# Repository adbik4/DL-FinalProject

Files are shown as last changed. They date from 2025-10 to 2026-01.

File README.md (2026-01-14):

# Dokumentacja projektu
## Schemat blokowy
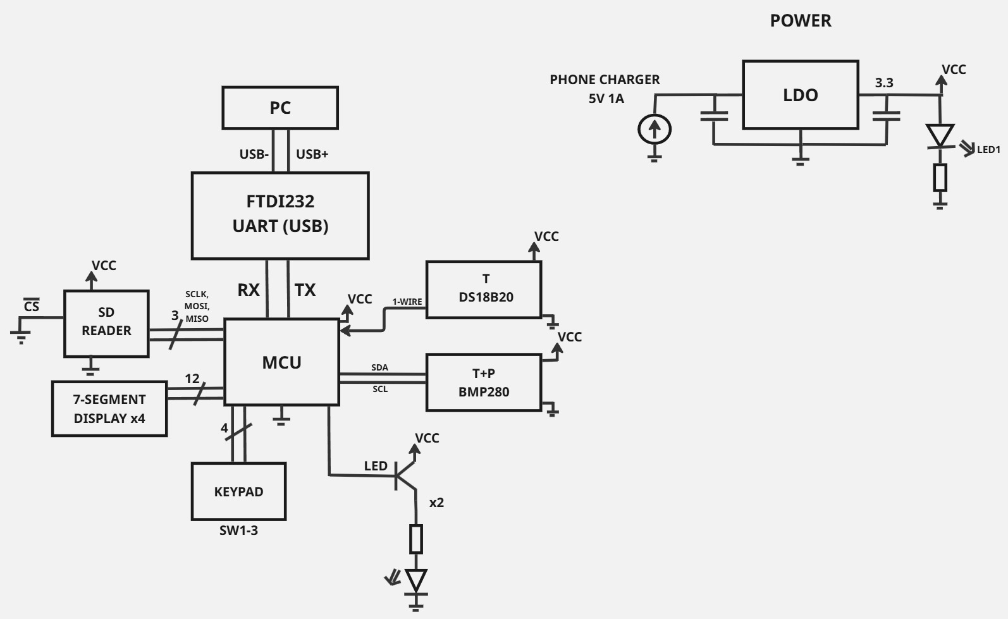
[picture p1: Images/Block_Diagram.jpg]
Schemat Blokowy


## Schemat ideowy
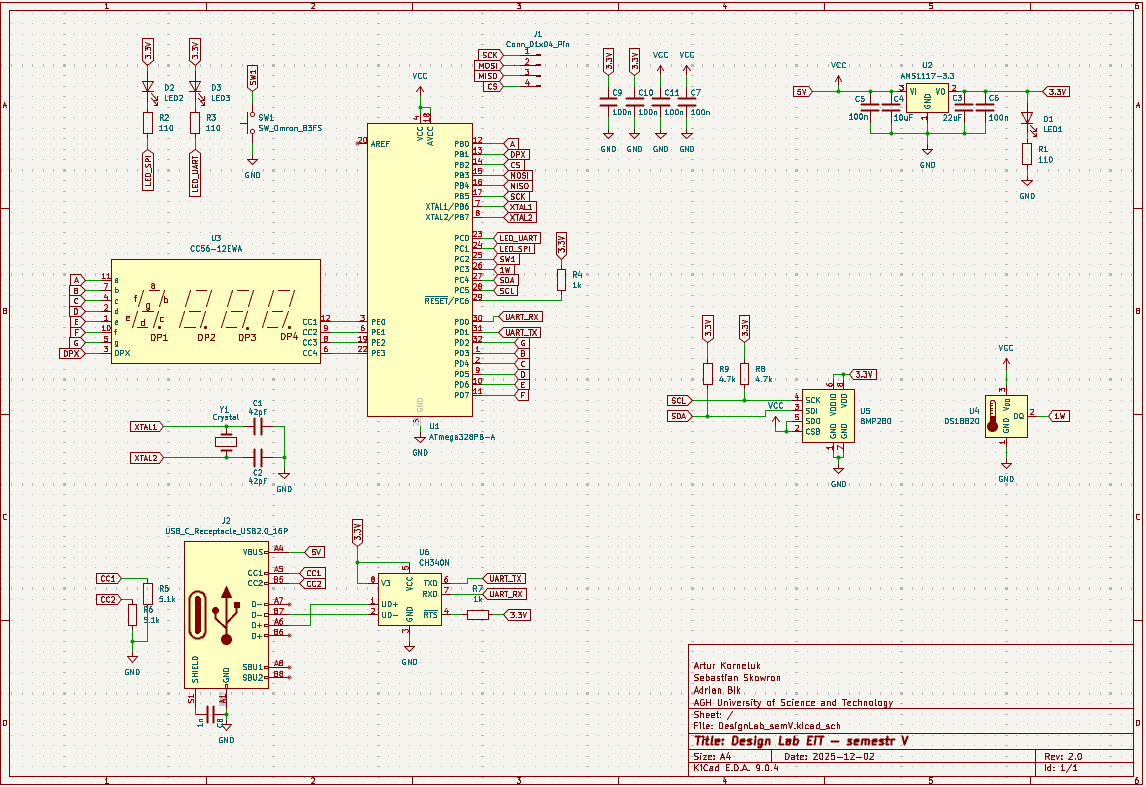
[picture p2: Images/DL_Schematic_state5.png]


## Design PCB
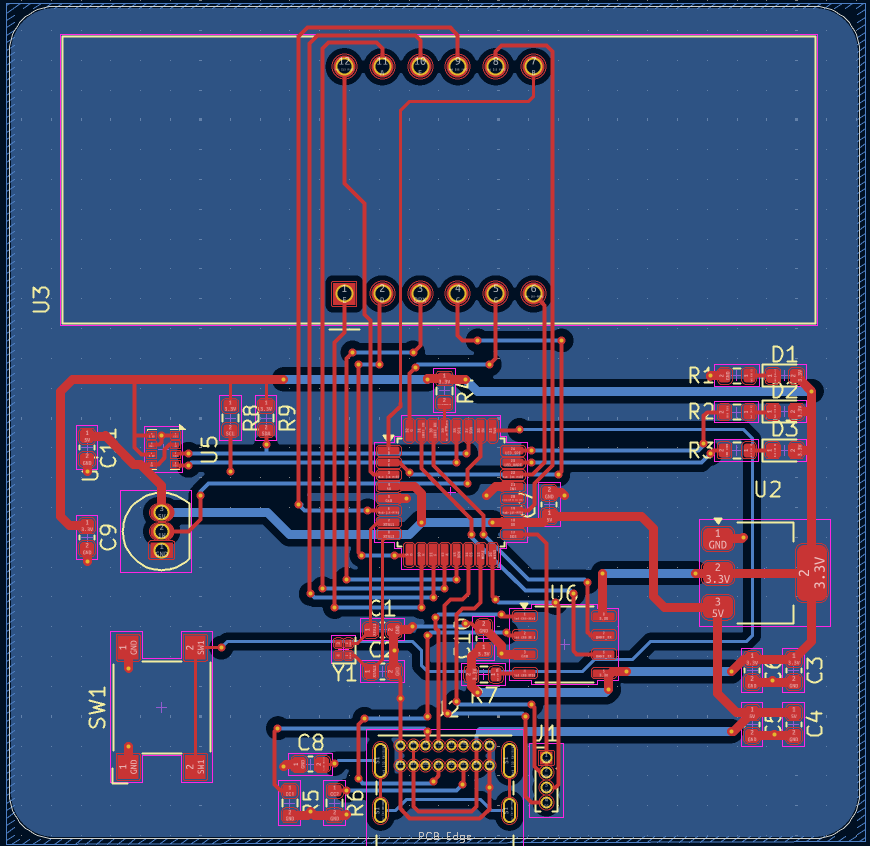
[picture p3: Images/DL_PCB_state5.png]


## Podgląd 3D
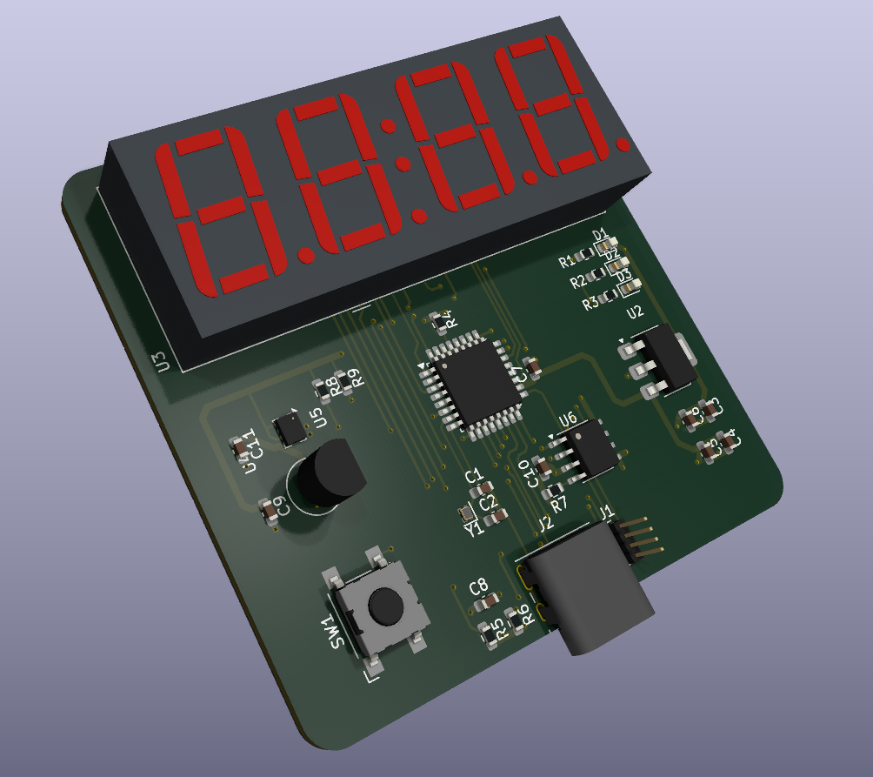
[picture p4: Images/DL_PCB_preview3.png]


### Blok mikrokontrolera (ATmega328PB)
*Obliczanie wartości pojemności C1 i C2 potrzebnych do zewnętrznego oscylatora MCU:*    

Wybraliśmy CY16BPS ponieważ jego parametry należą do najpopularniejszych do użycia w projektach z tym MCU.    
Oto jego najważniejsze parametry:   
- F_XTAL = 16 MHz
- C_load = 20 pF
- ESR = 50 ohm

Dla uproszczenia obliczeń, niech C1 = C2.    
Korzystając ze wzoru z dokumentacji ATmega,   
**C = 2 * C_L + C_S**  
gdzie     
C_L - Pojemnosć obciążenia kryształu,   
C_S - Pojemność pasożytnicza płytki PCB, niech wynosi 2 pF
    
Dla naszego kryształu C_L wynosi 20 pF    
**Stąd wynika, że C powinno mieć wartość około 42 pF.**

### Diody LED do sygnalizacji
*Obliczanie wartości rezystancji R1, R2 i R3 potrzebnych do uregulowania pracy diód:*     
    
Napięcie zasilania: 3.3V
Kolor diód LED: zielony co oznacza spadek napięcia około 2.2V   
Chcemy ustalić bezpieczny punkt pracy, powiedzmy 10mA    
Z prawa ohma: R = U / I = (3.3 - 2.2) / 10 mA = **110 ohm**

### Rezystancja podciągająca dla linii I2C
Wartość rezystancji podciągającej dla I2C jest wymianą pomiędzy możliwą prędkością wymiany danych a zużyciem energii.     

Zbyt mała wartość może uniemożliwić pinowi układu scalonego z którym się komunikujemy zwarcie linii z masą. Zalezy ona więc od najniższego napięcia jaka może być odczytana przez dany ukł. (U_OL) oraz prądu jaki jest on w stanie wytrzymać (I_OL).     

**R_min = (V_CC - U_OLmax) / I_OL**     

Zbyt duża zaś, przy dużych prędkościach może nie nadążyć z naładowaniem pojemności magistrali (C_m) przed nadejściem kolejnego stanu niskiego. W związku z tym, zależy ona od czasu narastania zboczy.     

**R_max = t_r / (0.8473 * C_m)**     
*Wartość 0.8473 = -ln(0.3) wynika z czasu ładowania pojemności od  30% - 70%*     

Przy naszych małych prędkościach komunikacji oraz z pojedynczym urządzeniem na magistrali, przyjmiemy standardową wartość **4.7kΩ.**

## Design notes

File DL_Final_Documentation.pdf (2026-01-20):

# AGH University of Krakow

# Documentation for the project

# Weather station

## from the course

# DESIGN LABORATORY

### Electronics and Telecommunications (PL), 3rd year

Adrian Bik | Sebastian Skowron | Artur Korneluk
| Thursday 8:00

Lecturer: dr inż. Jacek Stępień

15.01.2025

## 1. Project description

Project involves the design and implementation of a measurement and data logging system based on ATmega328pb microcontroller. The system is intended for measuring temperature and pressure using dedicated digital sensors: DS18B20 and BMP280. The captured data can be displayed on a 7-segment display and transmitted to a PC via USB-UART interface.
The system is designed in a modular way and implemented in stages, which allows for its gradual evolution and easy diagnostics of individual functional blocks. The project includes both hardware parts, such as schematic design and PCB layout, and software parts responsible for sensor handling, data presentation, data storage and user communication.

## 2. User manual

After a successful compilation, we can see the temperature from the BMP280 sensor displayed on a 7-segment display connected to the microcontroller. After a short press and hold of the S1 button on the keyboard, the pressure value is being displayed. Repeating this action, we get a temperature value from DS18B20 sensor, then we can come back to the first read. The UART-USB converter is used in order to enable communication between two PC`s by UART standard. We can receive the data from the sensors in terminal and additionally send messages from PC1 to PC2 (echo action).

## 3. Source files

Microchip Studio project contains:

- main.c, main.h - Main program of the project
- diodes.c, diodes.h - Led diodes control
- display.c, display.h - 7-segment display code
- uart.c, uart.h - Communication by UART standard
- sensors.c, sensors.h - BMP280, DS18B20 temperature and pressure sensors control

## 4. User Interface

The custom user interface designed for the weather station was written in the Python programming language. The application enables communication with the measurement device via serial COM port, while the current connection status is clearly presented to the user through a connected / disconnected status message.
The interface displays real-time measurement data captured from the weather station sensors, including temperature and pressure. These values are presented in standard physical units. Additionally, the application includes a log section that displays raw data frames received from the microcontroller. The interface also allows for sending custom text commands, enabling full diagnostics of the UART communication.
The current interface architecture provides a solid basis for further system development, such as adding data logging to files or visualizing measurements using charts.

## 5. PCB

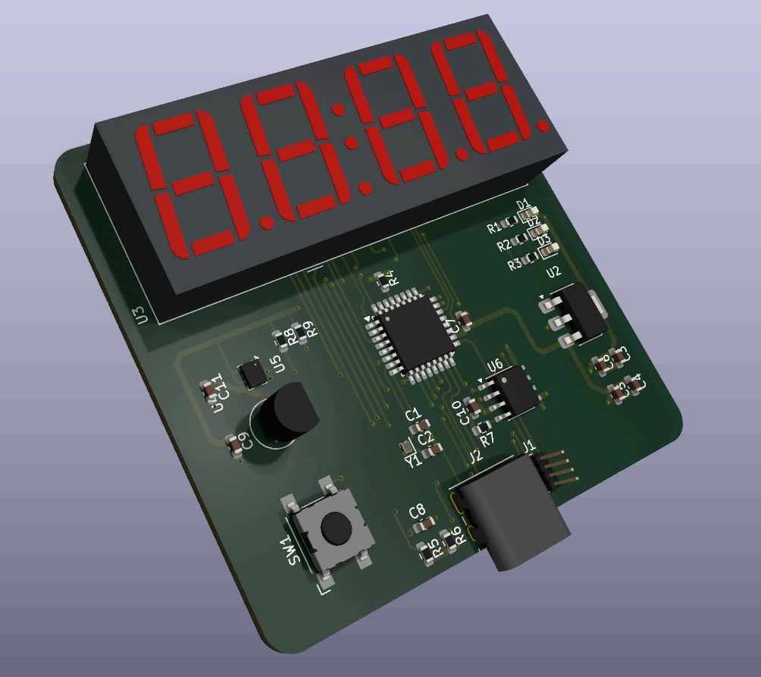
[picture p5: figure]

The full hardware documentation is located on github.
https://github.com/adbik4/DL-FinalProject

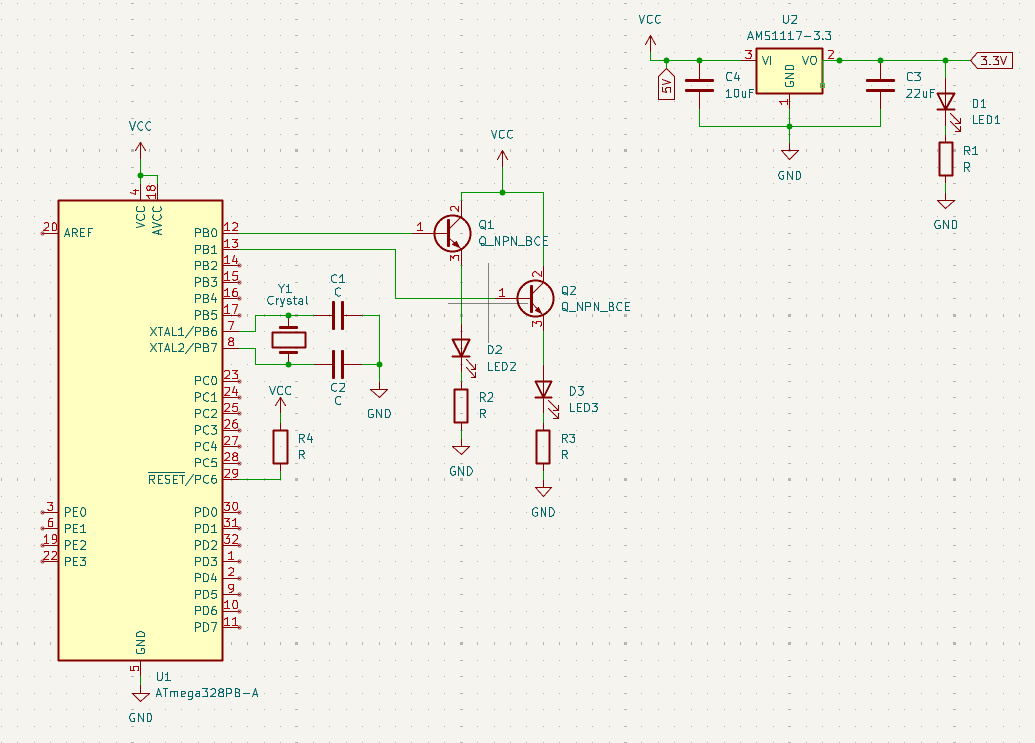
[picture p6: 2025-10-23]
Images/DL_Schematic_state1.png

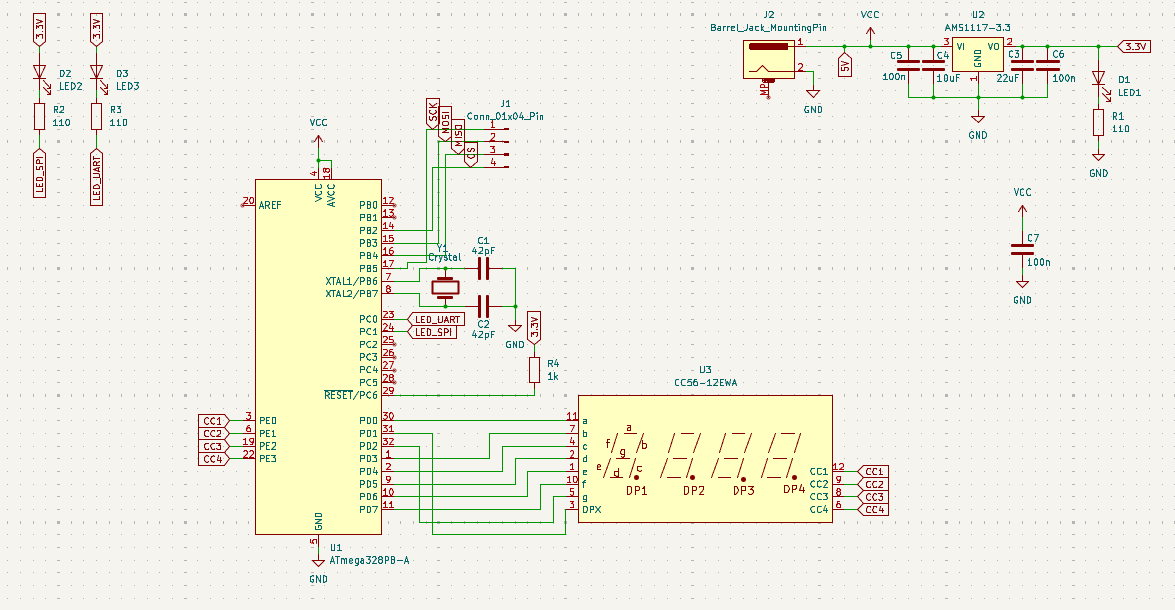
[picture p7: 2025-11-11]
Images/DL_Schematic_state3.png

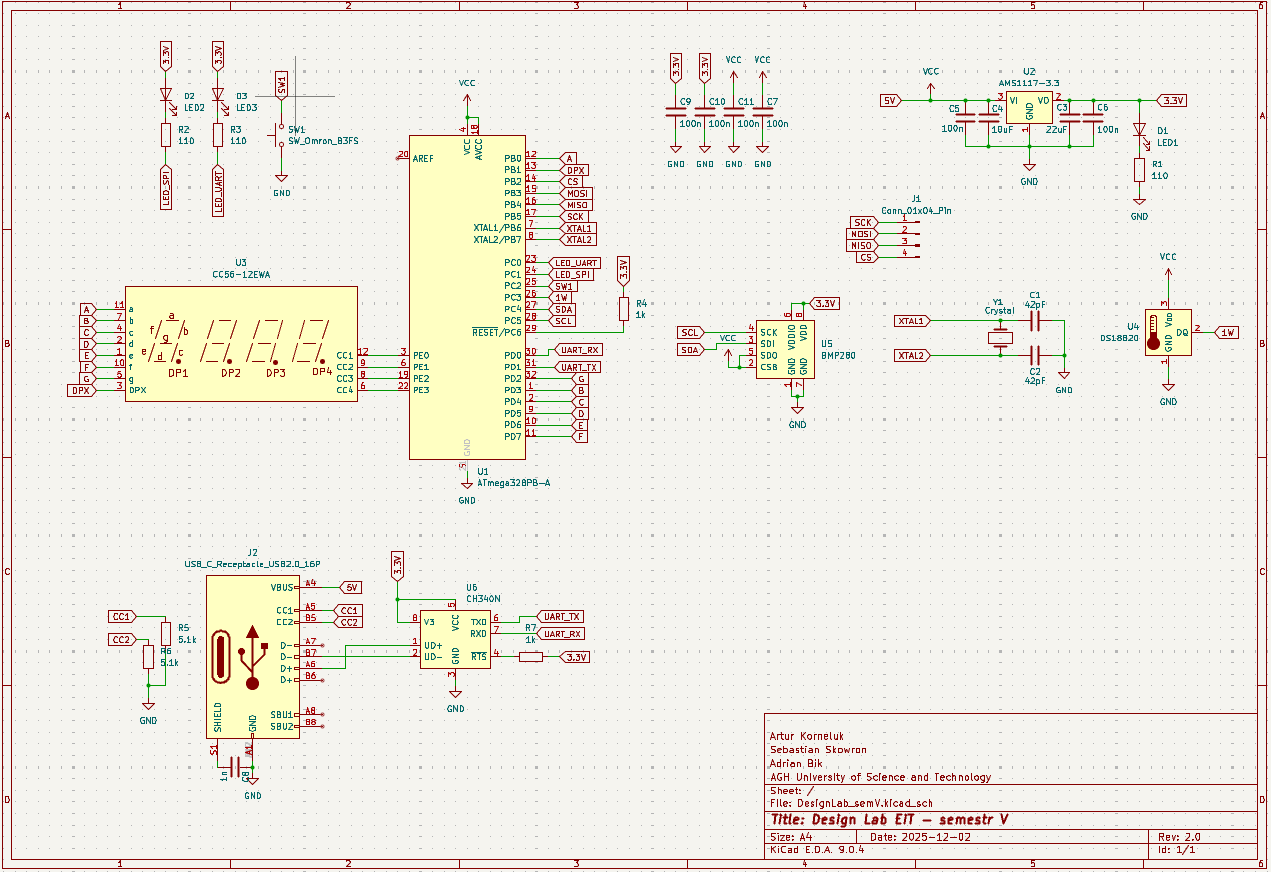
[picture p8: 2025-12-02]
Images/DL_Schematic_state4.png

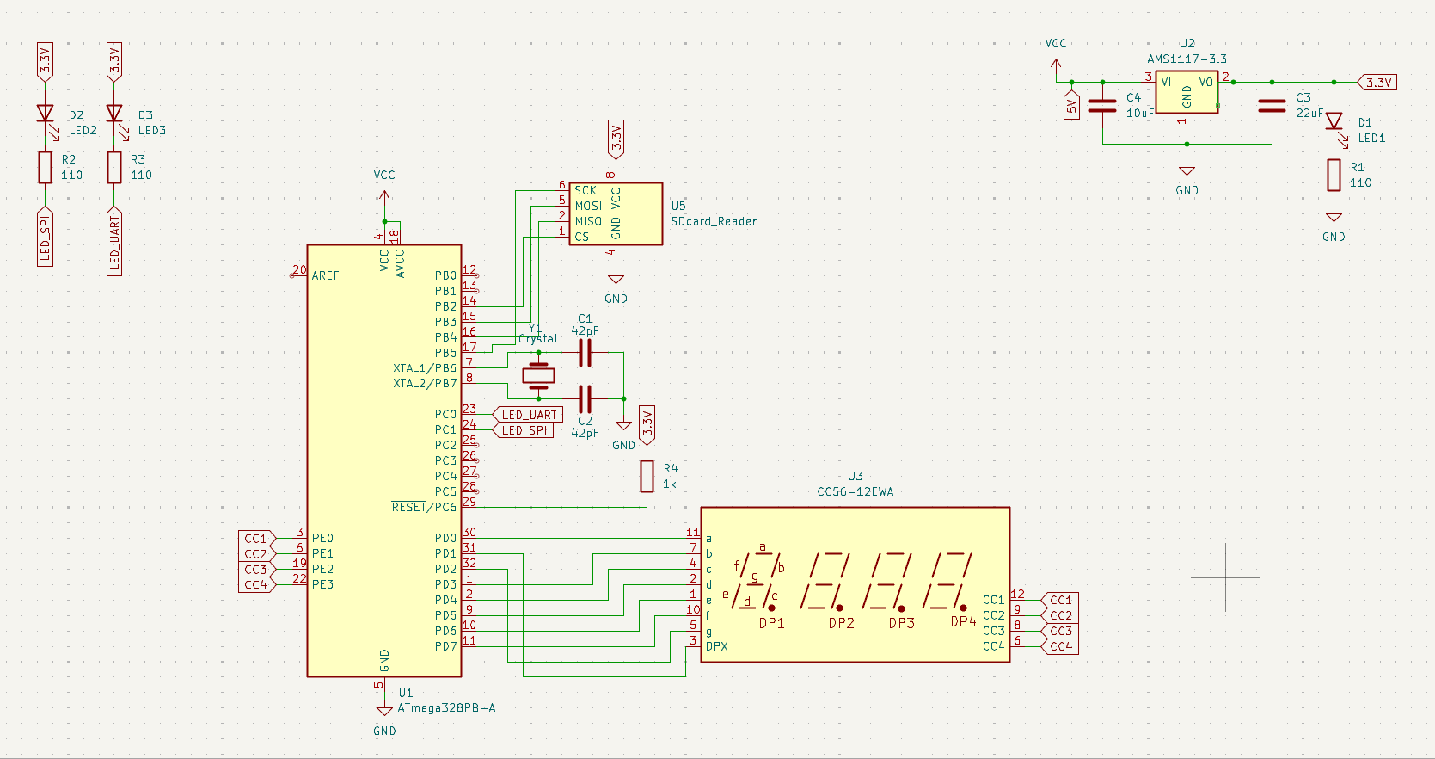
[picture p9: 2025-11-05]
Images/DL_Schematic_state2.png

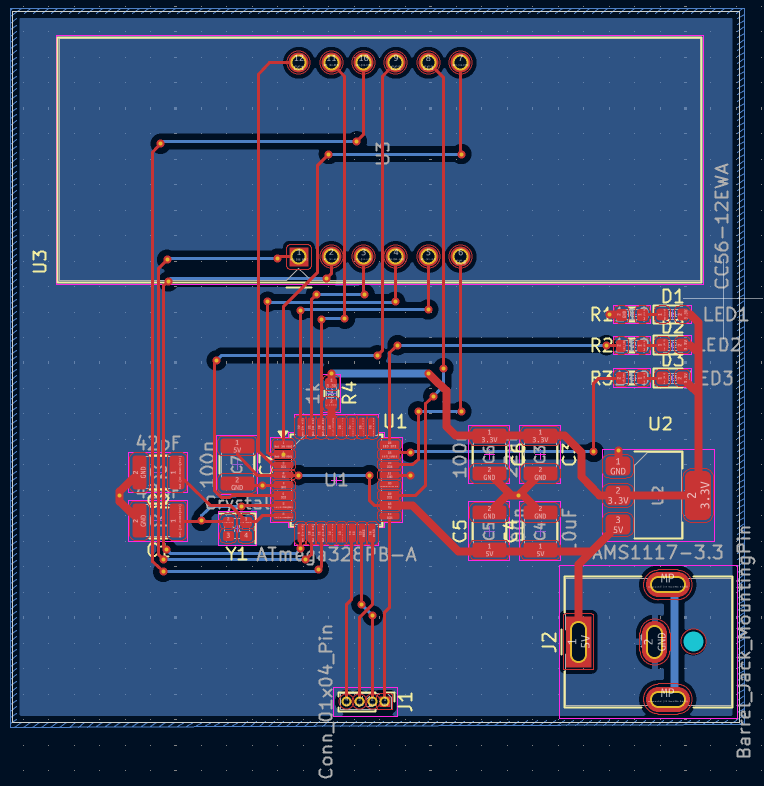
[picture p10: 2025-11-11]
Images/DL_PCB_state2.png

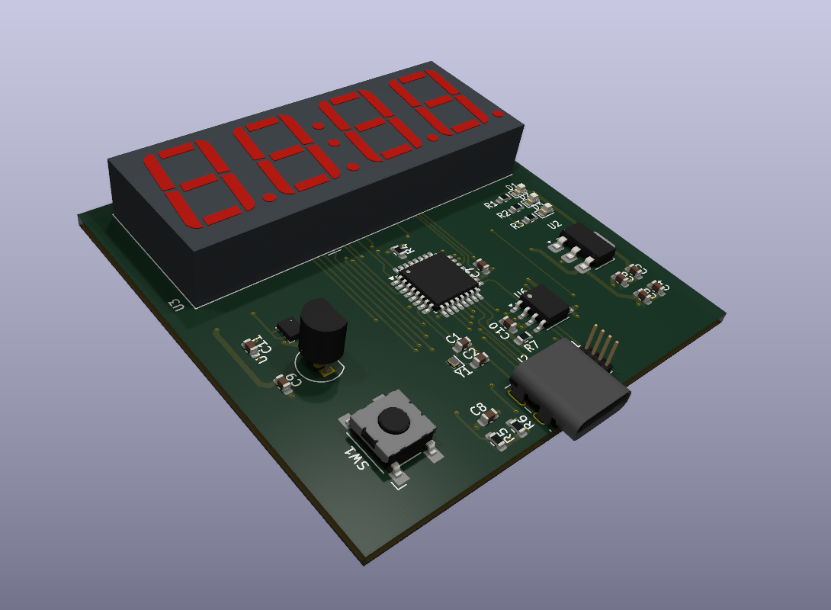
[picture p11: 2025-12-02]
Images/DL_PCB_preview2.png

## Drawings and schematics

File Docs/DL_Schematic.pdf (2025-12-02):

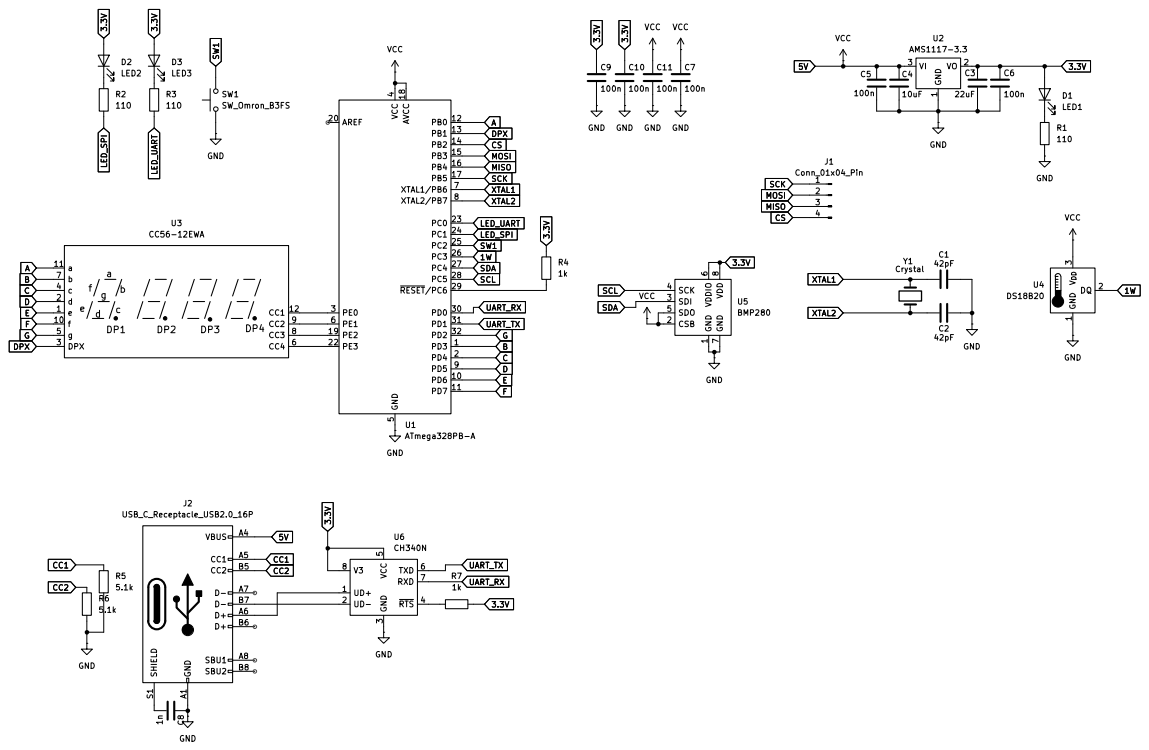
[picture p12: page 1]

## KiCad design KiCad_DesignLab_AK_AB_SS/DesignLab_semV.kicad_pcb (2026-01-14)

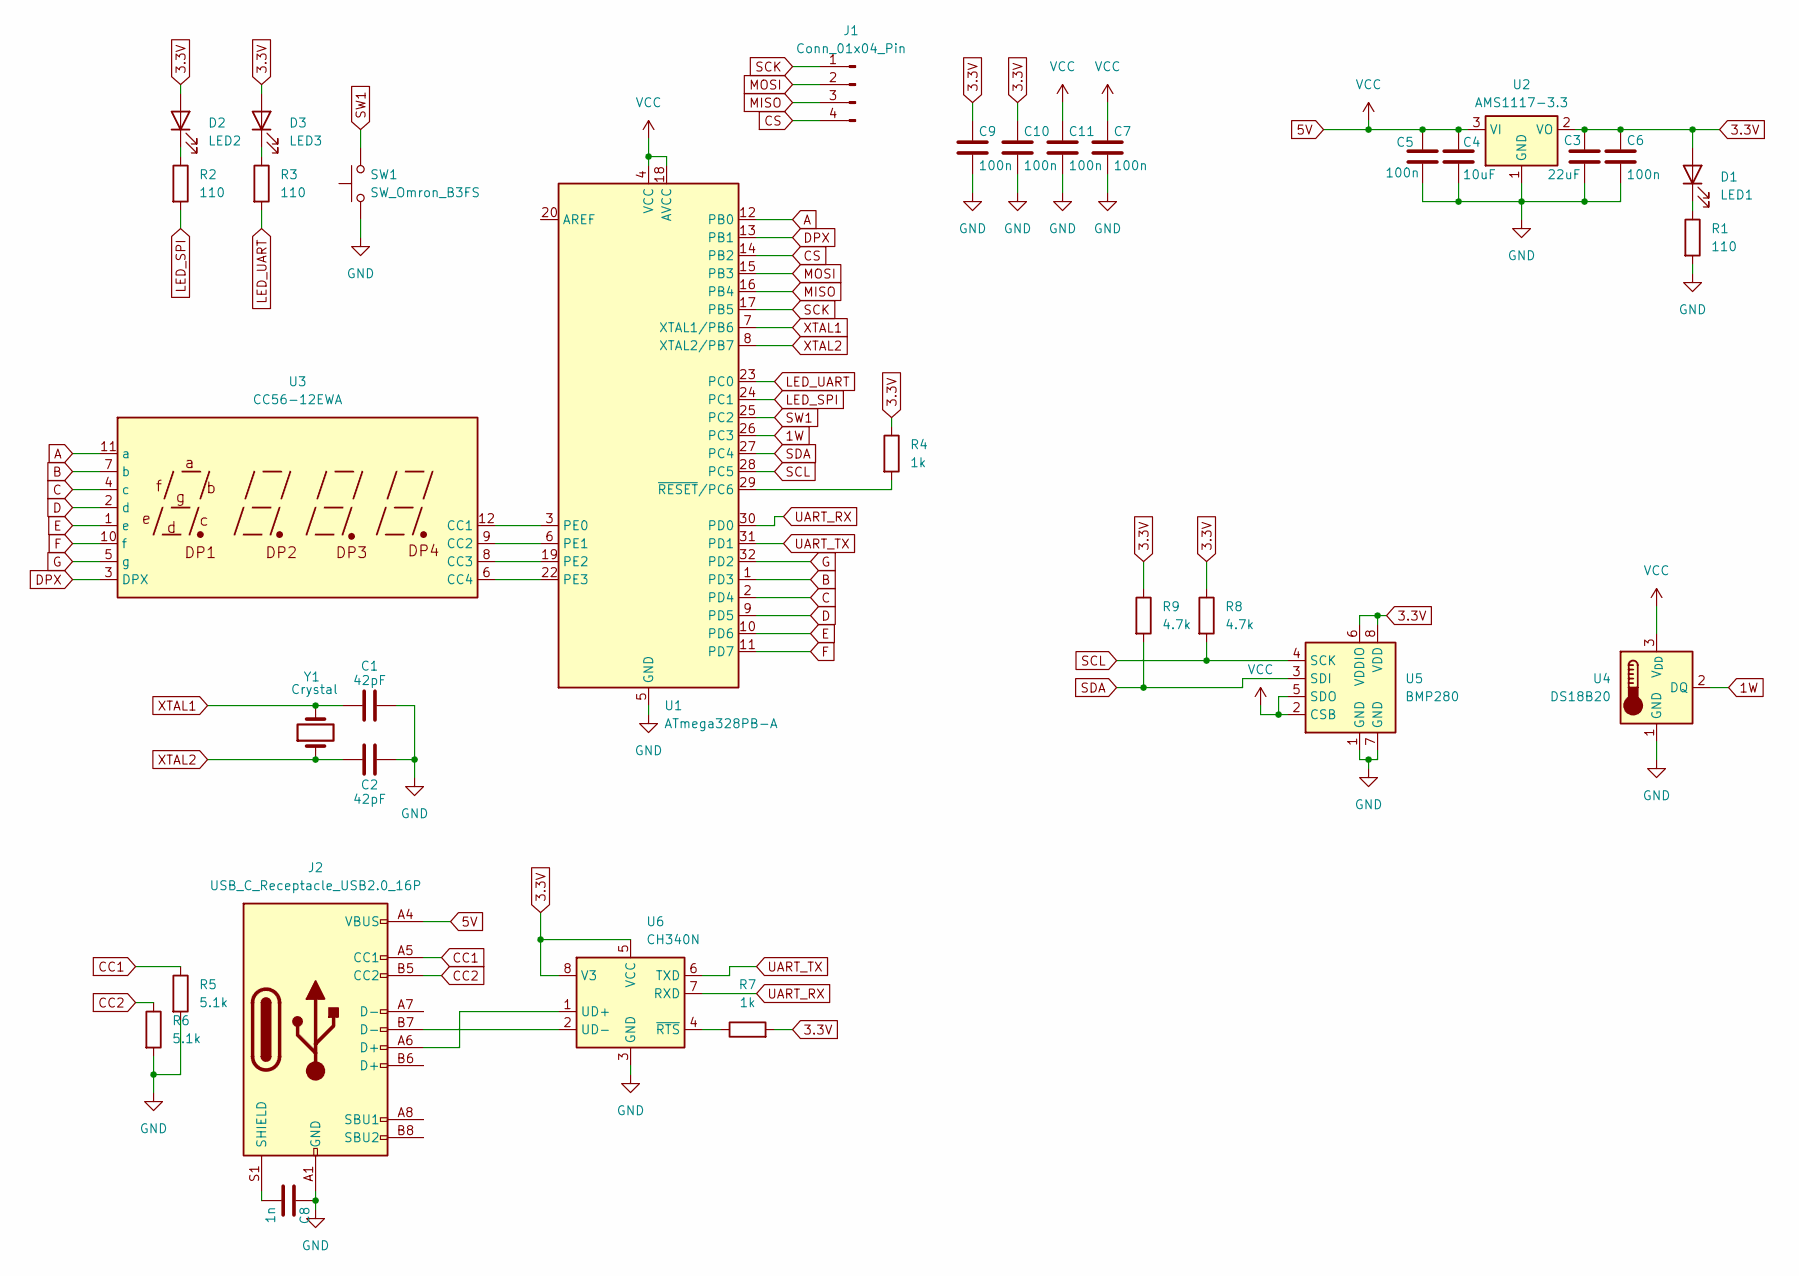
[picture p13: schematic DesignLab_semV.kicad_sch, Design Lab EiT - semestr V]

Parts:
C1, C2: 42pF; C_0603_1608Metric
C3: 22uF; C_0603_1608Metric
C4: 10uF; C_0603_1608Metric
C5, C6, C7, C9, C10, C11: 100n; C_0603_1608Metric
C8: 1n; C_0603_1608Metric
D1: LED1; LED_0603_1608Metric
D2: LED2; LED_0603_1608Metric
D3: LED3; LED_0603_1608Metric
J1: Conn_01x04_Pin; PinHeader_1x04_P1.00mm_Vertical
J2: USB_C_Receptacle_USB2.0_16P; USB_C_Receptacle_GCT_USB4085
R1, R2, R3: 110; R_0603_1608Metric
R4, R7: 1k; R_0603_1608Metric
R5, R6: 5.1k; R_0603_1608Metric
R8, R9: 4.7k; R_0603_1608Metric
SW1: SW_Omron_B3FS; SW_SPST_Omron_B3FS-100xP
U1: ATmega328PB-A; TQFP-32_7x7mm_P0.8mm
U2: AMS1117-3.3; SOT-223-3_TabPin2
U3: CC56-12EWA; CA56-12EWA
U4: DS18B20; TO-92_Inline
U5: BMP280; Bosch_LGA-8_2x2.5mm_P0.65mm_ClockwisePinNumbering
U6: CH340N; JEITA_SOIC-8_3.9x4.9mm_P1.27mm
Y1: Crystal; Crystal_SMD_1210-4Pin_1.2x1.0mm

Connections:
1W: U1.26 (PC3), U4.2 (DQ)
3.3V: C3.1, C6.1, C9.1, C10.1, D1.2 (A), D2.2 (A), D3.2 (A), R4.1, R7.2, R8.1, R9.1, U2.2 (VO), U5.6 (VDDIO), U5.8 (VDD), U6.5 (VCC), U6.8 (V3)
5V: C4.1, C5.1, C7.1, C11.1, J2.A4 (VBUS), J2.A9 (VBUS), J2.B4 (VBUS), J2.B9 (VBUS), U1.4 (VCC), U1.18 (AVCC), U2.3 (VI), U4.3 (V_{DD}), U5.2 (CSB), U5.5 (SDO)
A: U1.12 (PB0), U3.11 (a)
B: U1.1 (PD3), U3.7 (b)
C: U1.2 (PD4), U3.4 (c)
CC1: J2.A5 (CC1), R5.1
CC2: J2.B5 (CC2), R6.1
CS: J1.4, U1.14 (PB2)
D: U1.9 (PD5), U3.2 (d)
DPX: U1.13 (PB1), U3.3 (DPX)
E: U1.10 (PD6), U3.1 (e)
F: U1.11 (PD7), U3.10 (f)
G: U1.32 (PD2), U3.5 (g)
GND: C1.2, C2.2, C3.2, C4.2, C5.2, C6.2, C7.2, C8.1, C9.2, C10.2, C11.2, J2.A1 (GND), J2.A12 (GND), J2.B1 (GND), J2.B12 (GND), R1.2, R5.2, R6.2, SW1.1, U1.5 (GND), U1.21 (GND), U2.1 (GND), U4.1 (GND), U5.1 (GND), U5.7 (GND), U6.3 (GND)
LED_SPI: R2.2, U1.24 (PC1)
LED_UART: R3.2, U1.23 (PC0)
MISO: J1.3, U1.16 (PB4)
MOSI: J1.2, U1.15 (PB3)
unnamed: D1.1 (K), R1.1
unnamed: D2.1 (K), R2.1
unnamed: D3.1 (K), R3.1
unnamed: C8.2, J2.S1 (SHIELD)
unnamed: U1.3 (PE0), U3.12 (CC1)
unnamed: U1.6 (PE1), U3.9 (CC2)
unnamed: U1.19 (PE2), U3.8 (CC3)
unnamed: U1.22 (PE3), U3.6 (CC4)
unnamed: R4.2, U1.29 (~RESET/PC6)
unnamed: J2.A6 (D+), U6.1 (UD+)
unnamed: J2.B7 (D-), U6.2 (UD-)
unnamed: R7.1, U6.4 (~RTS)
SCK: J1.1, U1.17 (PB5)
SCL: R8.2, U1.28 (PC5), U5.4 (SCK)
SDA: R9.2, U1.27 (PC4), U5.3 (SDI)
SW1: SW1.2, U1.25 (PC2)
UART_RX: U1.30 (PD0), U6.7 (RXD)
UART_TX: U1.31 (PD1), U6.6 (TXD)
XTAL1: C1.1, U1.7 (XTAL1/PB6), Y1.2
XTAL2: C2.1, U1.8 (XTAL2/PB7), Y1.1

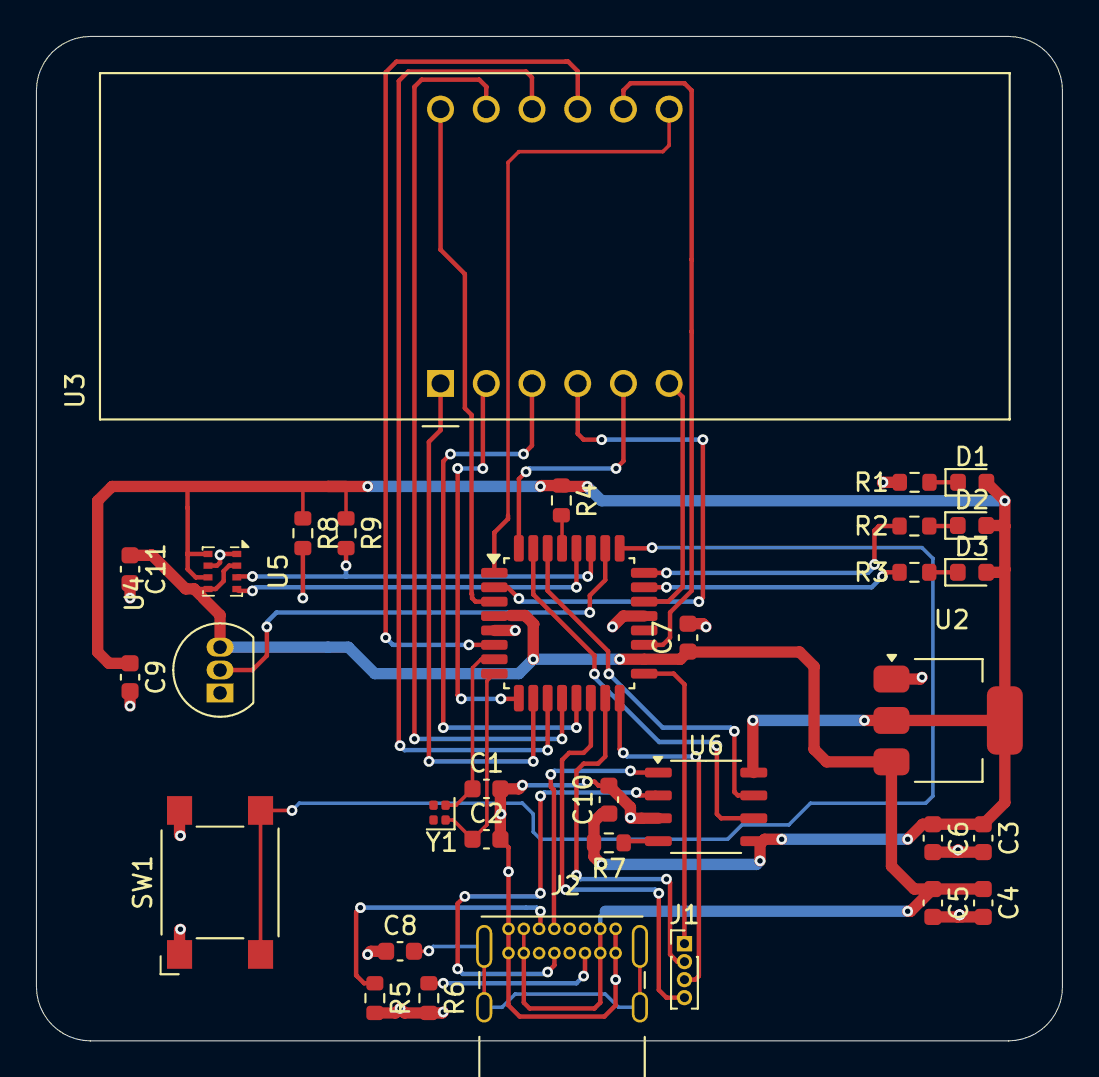
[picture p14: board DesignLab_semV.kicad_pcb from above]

Board: 2 copper layers, 57.0 x 55.8 mm, 33 parts (0 on the bottom side), 39 nets.

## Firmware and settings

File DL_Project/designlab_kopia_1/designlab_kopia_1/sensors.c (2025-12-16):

#include "sensors.h"
#include "main.h"


volatile display_mode_t display_mode = DISPLAY_BMP_TEMPERATURE;

// Calibration parameters for BMP280
uint16_t dig_T1;
int16_t dig_T2;
int16_t dig_T3;
uint16_t dig_P1;
int16_t dig_P2;
int16_t dig_P3;
int16_t dig_P4;
int16_t dig_P5;
int16_t dig_P6;
int16_t dig_P7;
int16_t dig_P8;
int16_t dig_P9;
int32_t t_fine;

// ============= DS18B20 Functions =============

void DS18B20_SetPinOutput(void) {
	DS18B20_DDR |= (1 << DS18B20_DQ);
}

void DS18B20_SetPinInput(void) {
	DS18B20_DDR &= ~(1 << DS18B20_DQ);
}

void DS18B20_SetPinLow(void) {
	DS18B20_PORT &= ~(1 << DS18B20_DQ);
}

void DS18B20_SetPinHigh(void) {
	DS18B20_PORT |= (1 << DS18B20_DQ);
}

uint8_t DS18B20_ReadPin(void) {
	return (DS18B20_PIN & (1 << DS18B20_DQ)) ? 1 : 0;
}

uint8_t DS18B20_Reset(void) {
	uint8_t response;
	
	DS18B20_SetPinOutput();
	DS18B20_SetPinLow();
	_delay_us(480);
	
	DS18B20_SetPinInput();
	DS18B20_SetPinHigh();
	_delay_us(70);
	
	response = DS18B20_ReadPin();
	_delay_us(410);
	
	return response;
}

void DS18B20_WriteBit(uint8_t bit) {
	DS18B20_SetPinOutput();
	DS18B20_SetPinLow();
	_delay_us(1);
	
	if (bit) {
		DS18B20_SetPinHigh();
	}
	
	_delay_us(60);
	DS18B20_SetPinHigh();
	_delay_us(1);
}

uint8_t DS18B20_ReadBit(void) {
	uint8_t bit = 0;
	
	DS18B20_SetPinOutput();
	DS18B20_SetPinLow();
	_delay_us(1);
	
	DS18B20_SetPinInput();
	DS18B20_SetPinHigh();
	_delay_us(14);
	
	if (DS18B20_ReadPin()) {
		bit = 1;
	}
	
	_delay_us(45);
	
	return bit;
}

void DS18B20_WriteByte(uint8_t byte) {
	for (uint8_t i = 0; i < 8; i++) {
		DS18B20_WriteBit(byte & 0x01);
		byte >>= 1;
	}
}

uint8_t DS18B20_ReadByte(void) {
	uint8_t byte = 0;
	
	for (uint8_t i = 0; i < 8; i++) {
		byte >>= 1;
		if (DS18B20_ReadBit()) {
			byte |= 0x80;
		}
	}
	
	return byte;
}

int16_t DS18B20_ReadTemperature(void) {
	uint8_t temp_lsb, temp_msb;
	int16_t temp;
	
	// Reset and check presence
	if (DS18B20_Reset()) {
		return -9999; 
	}
	
	// Skip ROM 
	DS18B20_WriteByte(DS18B20_CMD_SKIPROM);
	
	// Start temperature conversion
	DS18B20_WriteByte(DS18B20_CMD_CONVERTTEMP);
	
	// Wait for conversion (750ms for 12-bit resolution)
	_delay_ms(750);
	
	// Reset again
	if (DS18B20_Reset()) {
		return -9999; // Error
	}
	
	// Skip ROM
	DS18B20_WriteByte(DS18B20_CMD_SKIPROM);
	
	// Read scratchpad
	DS18B20_WriteByte(DS18B20_CMD_RSCRATCHPAD);
	
	// Read temperature bytes
	temp_lsb = DS18B20_ReadByte();
	temp_msb = DS18B20_ReadByte();
	
	// Combine bytes
	temp = (temp_msb << 8) | temp_lsb;
	
	// Convert to 0.1°C resolution

	return (temp * 10) / 16;
}

// ============= I2C Functions =============

void I2C_Init(void) {
	// Set I2C bit rate
	TWSR0 = 0x00; // Prescaler = 1
	TWBR0 = ((F_CPU / SCL_CLOCK) - 16) / 2;
	
	// Enable TWI
	TWCR0 = (1 << TWEN);
}

void I2C_Start(void) {
	TWCR0 = (1 << TWINT) | (1 << TWSTA) | (1 << TWEN);
	while (!(TWCR0 & (1 << TWINT)));
}

void I2C_Stop(void) {
	TWCR0 = (1 << TWINT) | (1 << TWSTO) | (1 << TWEN);
	_delay_us(100);
}

void I2C_Write(uint8_t data) {
	TWDR0 = data;
	TWCR0 = (1 << TWINT) | (1 << TWEN);
	while (!(TWCR0 & (1 << TWINT)));
}

uint8_t I2C_Read_ACK(void) {
	TWCR0 = (1 << TWINT) | (1 << TWEN) | (1 << TWEA);
	while (!(TWCR0 & (1 << TWINT)));
	return TWDR0;
}

uint8_t I2C_Read_NACK(void) {
	TWCR0 = (1 << TWINT) | (1 << TWEN);
	while (!(TWCR0 & (1 << TWINT)));
	return TWDR0;
}

// ============= BMP280 Functions =============

void BMP280_WriteReg(uint8_t reg, uint8_t value) {
	I2C_Start();
	I2C_Write((BMP280_ADDR << 1) | 0); // Write mode
	I2C_Write(reg);
	I2C_Write(value);
	I2C_Stop();
}

uint8_t BMP280_ReadReg(uint8_t reg) {
	uint8_t value;
	
	I2C_Start();
	I2C_Write((BMP280_ADDR << 1) | 0); // Write mode
	I2C_Write(reg);
	I2C_Start(); // Repeated start
	I2C_Write((BMP280_ADDR << 1) | 1); // Read mode
	value = I2C_Read_NACK();
	I2C_Stop();
	
	return value;
}

void BMP280_ReadCalibration(void) {
	uint8_t calib[24];
	
	// Read all calibration data
	I2C_Start();
	I2C_Write((BMP280_ADDR << 1) | 0);
	I2C_Write(BMP280_REG_DIG_T1_LSB);
	I2C_Start();
	I2C_Write((BMP280_ADDR << 1) | 1);
	
	for (uint8_t i = 0; i < 23; i++) {
		calib[i] = I2C_Read_ACK();
	}
	calib[23] = I2C_Read_NACK();
	I2C_Stop();
	
	// Temperature calibration
	dig_T1 = (calib[1] << 8) | calib[0];
	dig_T2 = (calib[3] << 8) | calib[2];
	dig_T3 = (calib[5] << 8) | calib[4];
	
	// Pressure calibration
	dig_P1 = (calib[7] << 8) | calib[6];
	dig_P2 = (calib[9] << 8) | calib[8];
	dig_P3 = (calib[11] << 8) | calib[10];
	dig_P4 = (calib[13] << 8) | calib[12];
	dig_P5 = (calib[15] << 8) | calib[14];
	dig_P6 = (calib[17] << 8) | calib[16];
	dig_P7 = (calib[19] << 8) | calib[18];
	dig_P8 = (calib[21] << 8) | calib[20];
	dig_P9 = (calib[23] << 8) | calib[22];
}

void BMP280_Init(void) {
	_delay_ms(100); 
	
	uint8_t id = BMP280_ReadReg(BMP280_REG_ID);
	if (id != 0x58) {
		
		return;
	}
	
	
	BMP280_WriteReg(BMP280_REG_RESET, 0xB6);
	_delay_ms(100);
	
	// Read calibration data
	BMP280_ReadCalibration();
	
	
	BMP280_WriteReg(BMP280_REG_CTRL_MEAS, 0x27);
	
	
	BMP280_WriteReg(BMP280_REG_CONFIG, 0xA0);
	
	_delay_ms(100);
}

int32_t BMP280_CompensateTemp(int32_t adc_T) {
	int32_t var1, var2, T;
	
	var1 = ((((adc_T >> 3) - ((int32_t)dig_T1 << 1))) * ((int32_t)dig_T2)) >> 11;
	var2 = (((((adc_T >> 4) - ((int32_t)dig_T1)) * ((adc_T >> 4) - ((int32_t)dig_T1))) >> 12) * ((int32_t)dig_T3)) >> 14;
	t_fine = var1 + var2;
	T = (t_fine * 5 + 128) >> 8;
	
	return T; // Temperature in 0.01 degrees Celsius
}

uint32_t BMP280_CompensatePressure(int32_t adc_P) {
	int64_t var1, var2, p;
	
	var1 = ((int64_t)t_fine) - 128000;
	var2 = var1 * var1 * (int64_t)dig_P6;
	var2 = var2 + ((var1 * (int64_t)dig_P5) << 17);
	var2 = var2 + (((int64_t)dig_P4) << 35);
	var1 = ((var1 * var1 * (int64_t)dig_P3) >> 8) + ((var1 * (int64_t)dig_P2) << 12);
	var1 = (((((int64_t)1) << 47) + var1)) * ((int64_t)dig_P1) >> 33;
	
	if (var1 == 0) {
		return 0; 
	}
	
	p = 1048576 - adc_P;
	p = (((p << 31) - var2) * 3125) / var1;
	var1 = (((int64_t)dig_P9) * (p >> 13) * (p >> 13)) >> 25;
	var2 = (((int64_t)dig_P8) * p) >> 19;
	p = ((p + var1 + var2) >> 8) + (((int64_t)dig_P7) << 4);
	
	return (uint32_t)p; 
}

int16_t BMP280_ReadTemperature(void) {
	uint8_t temp_data[3];
	int32_t adc_T;
	
	// Read temperature registers
	I2C_Start();
	I2C_Write((BMP280_ADDR << 1) | 0);
	I2C_Write(BMP280_REG_TEMP_MSB);
	I2C_Start();
	I2C_Write((BMP280_ADDR << 1) | 1);
	
	temp_data[0] = I2C_Read_ACK(); // MSB
	temp_data[1] = I2C_Read_ACK(); // LSB
	temp_data[2] = I2C_Read_NACK(); // XLSB
	I2C_Stop();
	
	// Combine into 20-bit value
	adc_T = ((int32_t)temp_data[0] << 12) | ((int32_t)temp_data[1] << 4) | ((int32_t)temp_data[2] >> 4);
	
	// Compensate temperature
	int32_t temp = BMP280_CompensateTemp(adc_T);
	
	return (int16_t)(temp / 10); // Convert to 0.1 degrees Celsius
}
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

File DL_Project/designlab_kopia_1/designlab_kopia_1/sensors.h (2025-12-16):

#ifndef SENSORS_H_
#define SENSORS_H_

#include <avr/io.h>

#define SCL_CLOCK 100000L

#define BMP280_ADDR 0x76

#define BMP280_REG_ID           0xD0
#define BMP280_REG_RESET        0xE0
#define BMP280_REG_STATUS       0xF3
#define BMP280_REG_CTRL_MEAS    0xF4
#define BMP280_REG_CONFIG       0xF5
#define BMP280_REG_PRESS_MSB    0xF7
#define BMP280_REG_TEMP_MSB     0xFA

#define BMP280_REG_DIG_T1_LSB   0x88
#define BMP280_REG_DIG_T1_MSB   0x89
#define BMP280_REG_DIG_T2_LSB   0x8A
#define BMP280_REG_DIG_T2_MSB   0x8B
#define BMP280_REG_DIG_T3_LSB   0x8C
#define BMP280_REG_DIG_T3_MSB   0x8D

#define BMP280_REG_DIG_P1_LSB   0x8E
#define BMP280_REG_DIG_P1_MSB   0x8F
#define BMP280_REG_DIG_P2_LSB   0x90
#define BMP280_REG_DIG_P2_MSB   0x91
#define BMP280_REG_DIG_P3_LSB   0x92
#define BMP280_REG_DIG_P3_MSB   0x93
#define BMP280_REG_DIG_P4_LSB   0x94
#define BMP280_REG_DIG_P4_MSB   0x95
#define BMP280_REG_DIG_P5_LSB   0x96
#define BMP280_REG_DIG_P5_MSB   0x97
#define BMP280_REG_DIG_P6_LSB   0x98
#define BMP280_REG_DIG_P6_MSB   0x99
#define BMP280_REG_DIG_P7_LSB   0x9A
#define BMP280_REG_DIG_P7_MSB   0x9B
#define BMP280_REG_DIG_P8_LSB   0x9C
#define BMP280_REG_DIG_P8_MSB   0x9D
#define BMP280_REG_DIG_P9_LSB   0x9E
#define BMP280_REG_DIG_P9_MSB   0x9F

#define DS18B20_PORT    PORTC
#define DS18B20_DDR     DDRC
#define DS18B20_PIN     PINC
#define DS18B20_DQ      PC3

#define DS18B20_CMD_CONVERTTEMP     0x44
#define DS18B20_CMD_RSCRATCHPAD     0xBE
#define DS18B20_CMD_SKIPROM         0xCC

#define BUTTON_PORT     PORTC
#define BUTTON_PIN      PINC
#define BUTTON_DDR      DDRC
#define BUTTON_BIT      PC2

typedef enum {
	DISPLAY_BMP_TEMPERATURE,
	DISPLAY_BMP_PRESSURE,
	DISPLAY_DS18B20_TEMPERATURE,
	DISPLAY_MODE_COUNT
} display_mode_t;




// DS18B20
uint8_t DS18B20_Reset(void);
void DS18B20_WriteByte(uint8_t byte);
uint8_t DS18B20_ReadByte(void);
int16_t DS18B20_ReadTemperature(void);

// I2C
void I2C_Init(void);
void I2C_Start(void);
void I2C_Stop(void);
void I2C_Write(uint8_t data);
uint8_t I2C_Read_ACK(void);
uint8_t I2C_Read_NACK(void);

// BMP280
void BMP280_Init(void);
uint8_t BMP280_ReadReg(uint8_t reg);
void BMP280_WriteReg(uint8_t reg, uint8_t value);
void BMP280_ReadCalibration(void);
int16_t BMP280_ReadTemperature(void);
uint16_t BMP280_ReadPressure(void);

// Button
void Button_Init(void);
uint8_t Button_IsPressed(void);

#endif /* SENSORS_H_ */

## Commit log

2025-10-19 Created the KiCad schematic
    [DesignLab_semV.kicad_sch]
2025-11-05 Updated the schematic & PCB with a 7seg display and SD card
    [DesignLab_semV.kicad_pcb, DesignLab_semV.kicad_sch]
2025-11-11 Routed power lines
    [DesignLab_semV.kicad_pcb, DesignLab_semV.kicad_sch]
2025-11-11 Finished routing the PCB
    [DesignLab_semV.kicad_pcb]
2025-11-20 Added UART implementation
2025-11-30 Updated the schematic with sensors
    [DesignLab_semV.kicad_sch]
2025-11-30 Fixed schematic + footprints
    [DesignLab_semV.kicad_pcb, DesignLab_semV.kicad_sch]
2025-11-30 Layout before routing
    [DesignLab_semV.kicad_pcb, DesignLab_semV.kicad_sch]
2025-11-30 sensors code
2025-11-30 Routed the power lines
    [DesignLab_semV.kicad_pcb]
2025-12-02 Completed PCB v2.0
    [DesignLab_semV.kicad_pcb, DesignLab_semV.kicad_sch]
2025-12-16 Updated the docs with i2c calculations
2025-12-16 PCB layout modifications
    [DesignLab_semV.kicad_pcb, DesignLab_semV.kicad_sch]
2026-01-14 Some DRC fixes
    [DesignLab_semV.kicad_pcb]
2026-01-14 Updated the PCB screenshot
